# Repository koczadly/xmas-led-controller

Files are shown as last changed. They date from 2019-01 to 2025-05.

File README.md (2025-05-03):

# Alrite?

## Introduction
This repository contains files from a personal project. The aim was to create a small microcontroller-driven LED module to replace a broken incandescent-based fibre optic Christmas tree. This is my first project involving PIC microcontrollers, and the second PCB I've designed; mistakes and questionable design techniques are to be expected.

### Files
- PCB files are in [`hardware`](/hardware/) (KiCad project)
- Software code is in [`firmware`](/firmware/) (MPLAB X project)

Feel free to re-use or modify this project to fit your needs, or use as a reference for PCB design or PIC software development.

## Finished product
A range of final images can be found in the [`media` folder](/media/).

Tree running program 1's animation
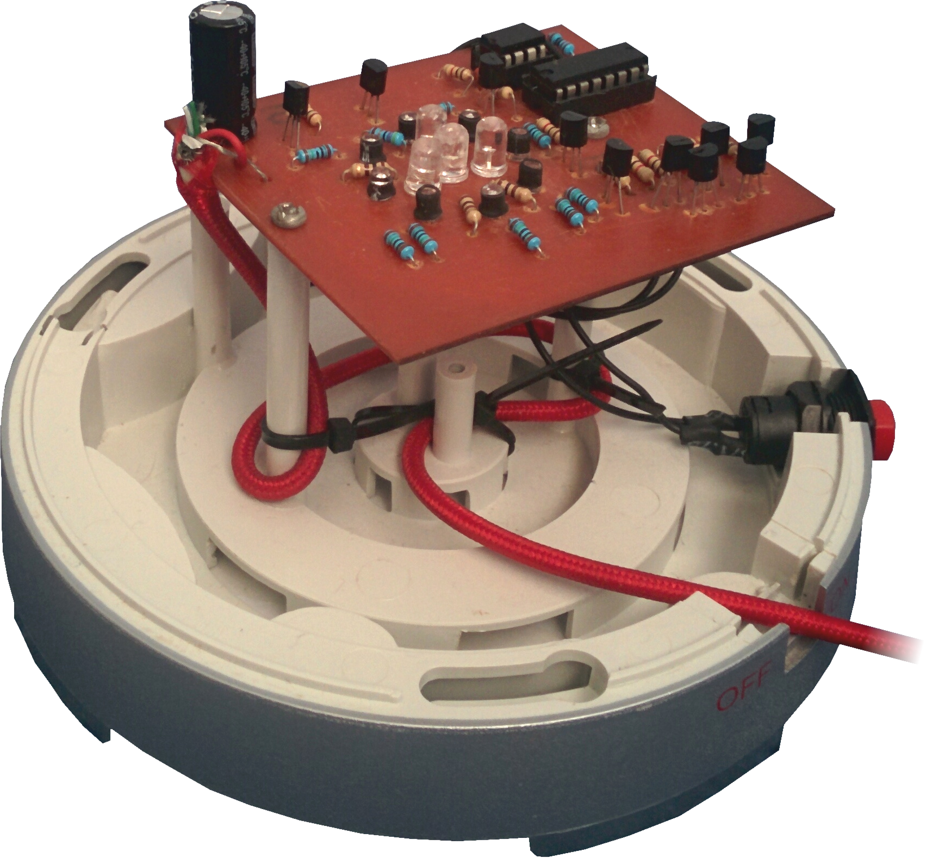
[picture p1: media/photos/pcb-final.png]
Finished PCB


## Bill of materials
MPN | Type | Quantity | Unit cost (GBP) | Purpose
--- | --- | --- | --- | ---
[**PIC12F683**](https://www.microchip.com/wwwproducts/en/PIC12F683) (DIP) | Microcontroller | 1 | £0.45 | Controls visual animations and user input
[**74HC595**](http://www.ti.com/lit/ds/symlink/sn74hc595.pdf) (DIP) | 8-bit Shift Register | 1 | £0.05 | Controls outputs to outer blue LEDs from the MCU
N/A | 3mm Blue LED | 8 | £0.01 | Outer LED ring
N/A | 5mm Green LED | 3 | £0.01 | Inner LEDs (PWM-driven)
N/A | 5mm White LED | 1 | £0.01 | Inner strobing LED
[**2N3904**](https://www.onsemi.com/pub/Collateral/2N3903-D.PDF) (TO-92) | NPN Transistor | 10 | £0.01 | Drives each individual controllable LED group (8x Blue, 1x Green, 1x White)
[N/A](https://www.ebay.co.uk/itm/AC-1-5A-250V-3A-125V-Red-Square-Momentary-SPST-Push-Button-Switch-6-Pcs/183740567110) | SPST Momentary Switch | 1 | £0.30 | User input for changing displayed animation/colour
N/A | 1000μF (25V) Electrolytic Capacitor | 1 | £0.10 | Supply voltage smoothing
N/A | 100nF (50V) Ceramic Capacitor | 1 | £0.01 | Decoupling capacitor for MCU
N/A | 10k Resistor (1/4W) | 1 | £0.001 | Input switch pull-down resistor
N/A | 1k Resistor (1/4W) | 10 | £0.001 | Transistor base current limiters
N/A | 150R Resistor (1/4W) | 8 | £0.001 | Current limiter for blue LEDs
N/A | 120R Resistor (1/4W) | 3 | £0.001 | Current limiter for green LEDs
N/A | 62R Resistor (1/4W) | 1 | £0.001 | Current limiter for white LED

<br>

**Total component cost: £1.15**  
**PCB panel cost (DIY): £0.35**  
**Total cost: £1.50** *(Not including etchant, solder or original tree product)*  

---

## Design notes & constraints
There were various constraints throughout this project, the most difficult one being that I could only produce a single-sided PCB, making overlaps impossible without using space for a 0Ω link. The size of the board was also restricted to *68mm x 92mm*, otherwise the module wouldn't fit into the tree's current plastic base housing. Drill holes also had to be made and inserted at defined locations so the board could easily be screwed into the unit using pre-existing screw mounts from the previous incandescent arrangement.

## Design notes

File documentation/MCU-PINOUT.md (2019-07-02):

# Microcontroller pinout

This project utilises a PIC12f683 microcontroller to control the animations and LEDs.
The pinout is as follows (following pin numbers specified in the datasheet):

Pin # | Name | Configuration | Function
--- | --- | --- | ---
1 | VDD | POWER | +5V power source
2 | GP5 | OUTPUT | Shift register serial data
3 | GP4 | OUTPUT | Shift register latch
4 | GP3 | INPUT | Program button (HIGH to change)
5 | GP2 | OUTPUT | Green LEDs (PWM-driven)
6 | GP1 | OUTPUT | Shift register serial clock
7 | GP0 | OUTPUT | White LED
8 | VSS | POWER | Ground

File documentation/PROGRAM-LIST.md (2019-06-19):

# Effects & animations
The current software version provides a total of 14 patterns, which can be changed by pressing the button (GP3 on U1).
The selected pattern will be retained when the power is cut in EEPROM memory address 0x00.

## List of effects
The following effects are available:
1. Sparkling blue + breathing green + flashing white (fast)
2. Sparkling blue + breathing green + flashing white (slow)
3. Sparkling blue + breathing green
4. Sparkling blue + static green
5. Sparkling blue
6. Breathing green
7. Breathing green + 100% blue
8. Breathing green + 50% blue
9. Static green
10. Static blue
11. Static aqua (green + 100% blue)
12. Static aqua (green + 50% blue)
13. Colour cycle (green/blue)
14. Colour cycle (green/blue/white)

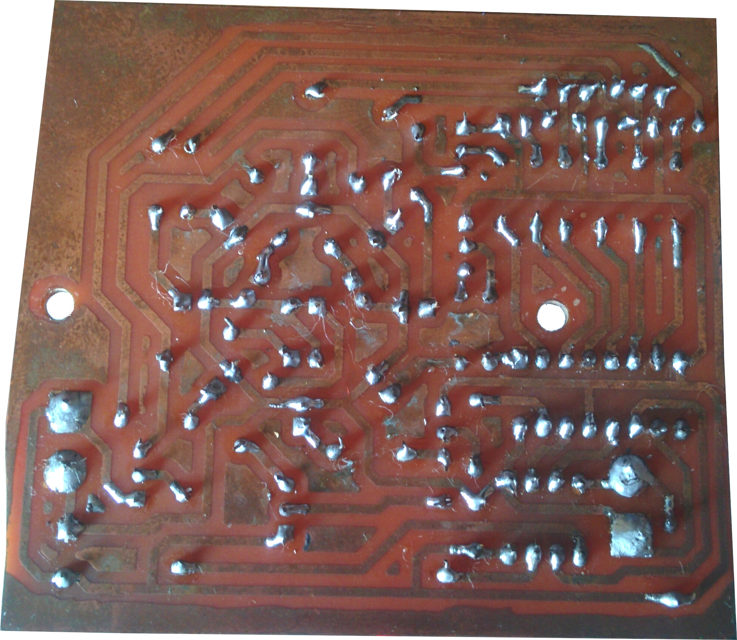
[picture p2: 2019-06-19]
media/photos/pcb-under.jpg

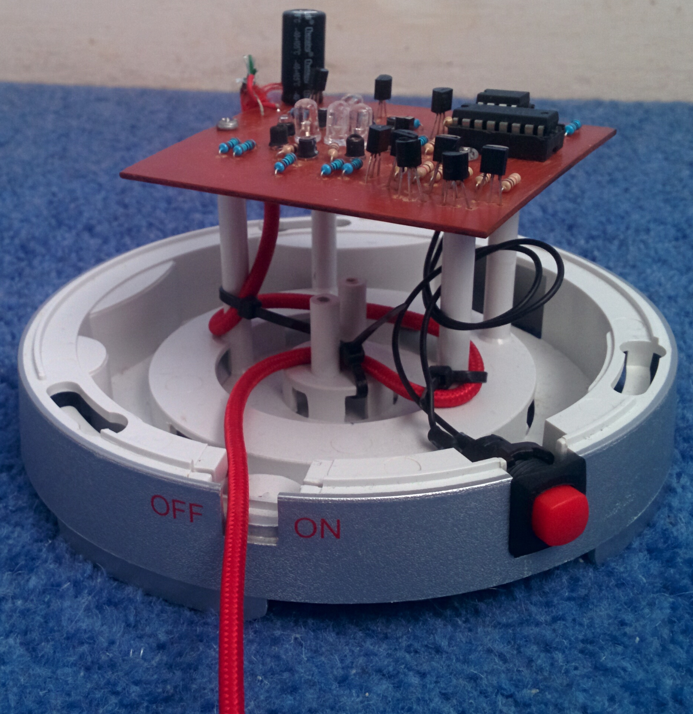
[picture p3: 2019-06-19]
media/photos/pcb-final-2.jpg

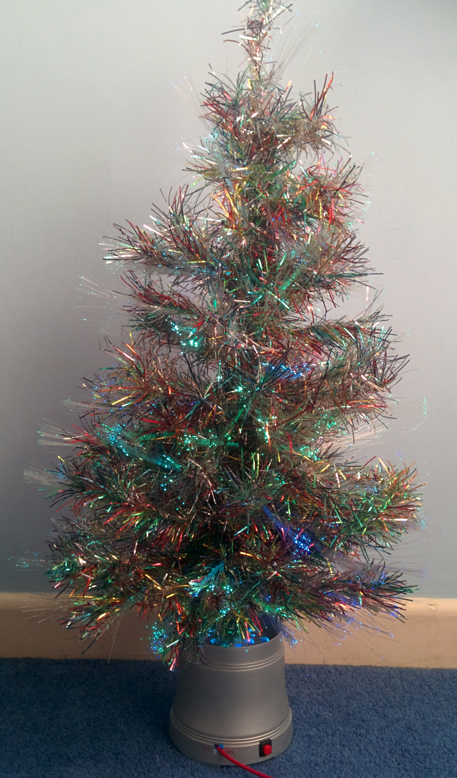
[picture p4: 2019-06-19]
media/photos/tree.jpg

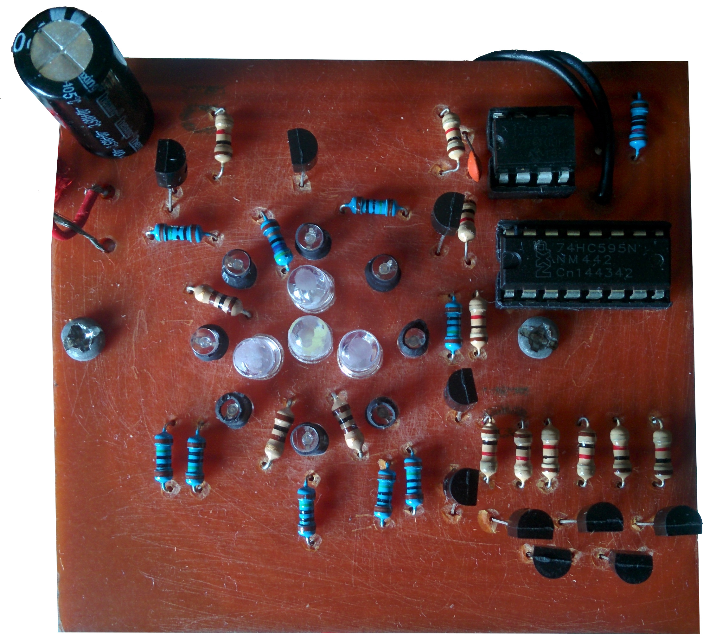
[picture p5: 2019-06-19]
media/photos/pcb-top.jpg

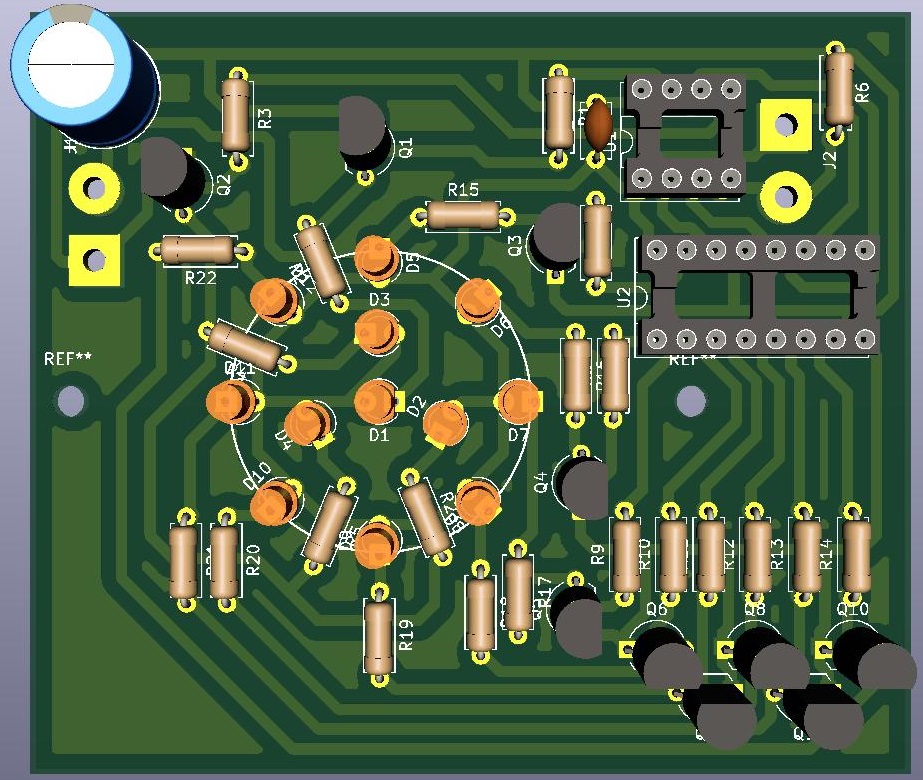
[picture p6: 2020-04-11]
media/renders/pcb-render-top.jpg

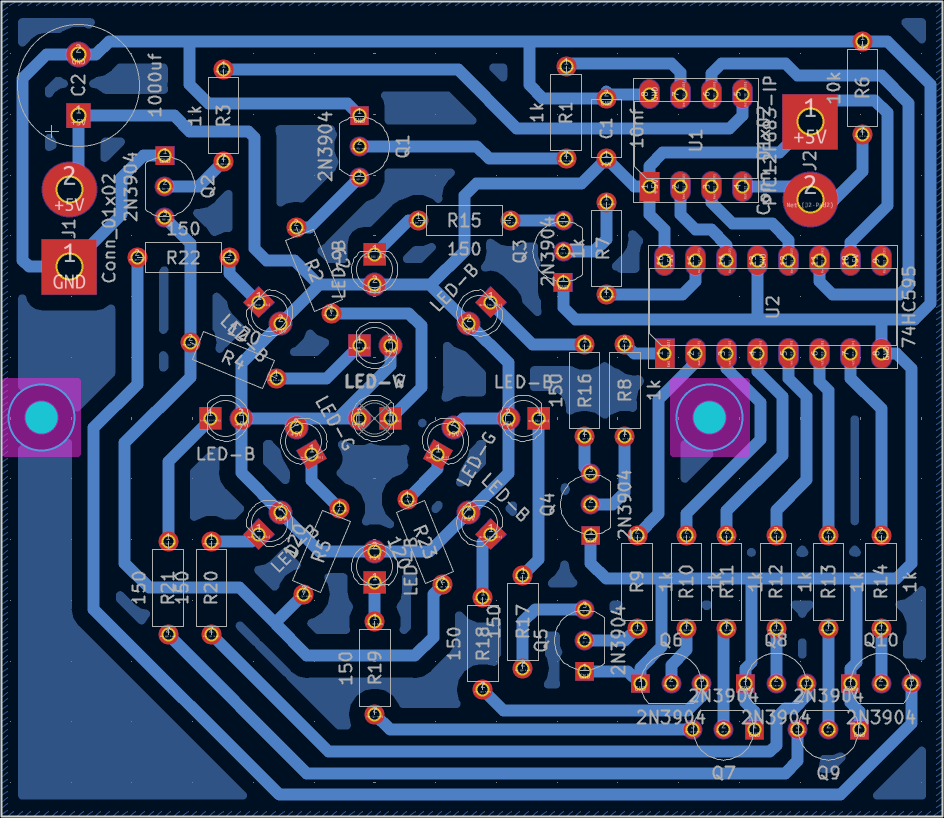
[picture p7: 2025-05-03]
media/renders/pcb-editor.png

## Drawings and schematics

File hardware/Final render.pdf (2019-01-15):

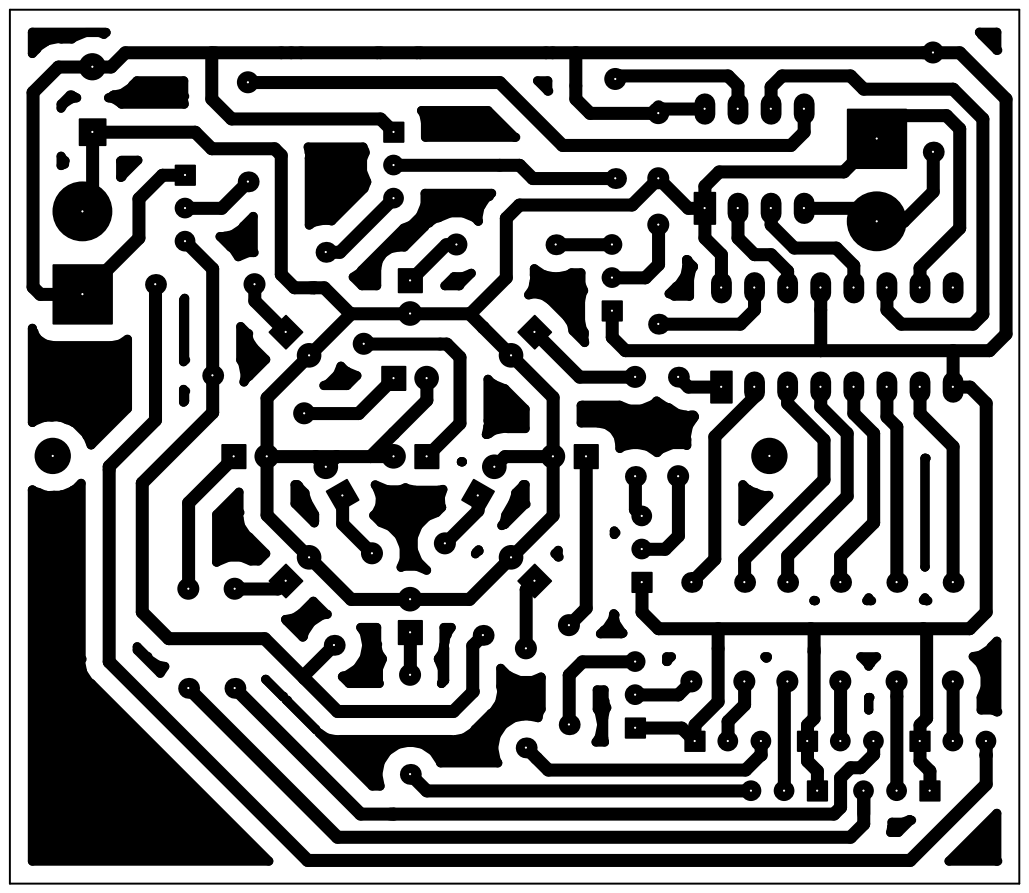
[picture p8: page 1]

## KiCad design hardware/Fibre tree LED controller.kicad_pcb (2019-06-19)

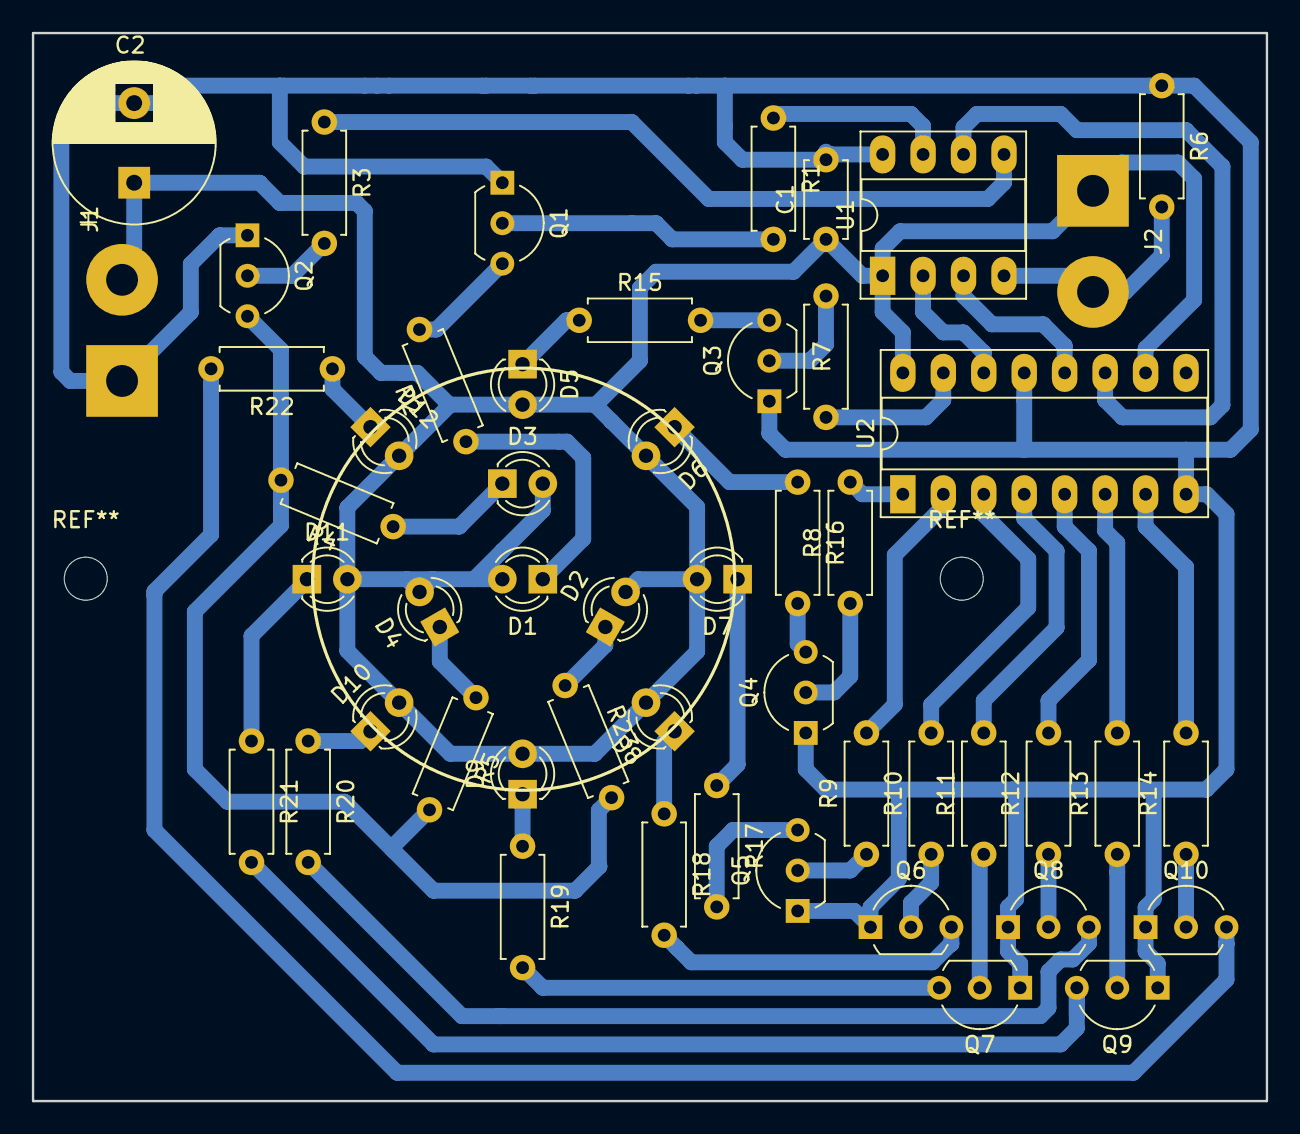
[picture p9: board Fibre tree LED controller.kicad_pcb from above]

Board: 2 copper layers, 77.5 x 67.1 mm, 51 parts (0 on the bottom side), 48 nets.

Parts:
C1: 10nf; C_Disc_D4.7mm_W2.5mm_P5.00mm
C2: 1000uf; CP_Radial_D10.0mm_P5.00mm
D1: LED-W; LED_D3.0mm_FlatTop
D2, D3, D4: LED-G; LED_D3.0mm_FlatTop
D5, D6, D7, D8, D9, D10, D11, D12: LED-B; LED_D3.0mm_FlatTop
J1, J2: Conn_01x02; SolderWirePad_1x02_P7.62mm_Drill2mm
Q1, Q2, Q3, Q4, Q5, Q6, Q7, Q8, Q9, Q10: 2N3904; TO-92L_Inline_Wide
R1, R3, R7, R8, R9, R10, R11, R12, R13, R14: 1k; R_Axial_DIN0207_L6.3mm_D2.5mm_P7.62mm_Horizontal
R2: 62; R_Axial_DIN0207_L6.3mm_D2.5mm_P7.62mm_Horizontal
R4, R5, R23: 120; R_Axial_DIN0207_L6.3mm_D2.5mm_P7.62mm_Horizontal
R6: 10k; R_Axial_DIN0207_L6.3mm_D2.5mm_P7.62mm_Horizontal
R15, R16, R17, R18, R19, R20, R21, R22: 150; R_Axial_DIN0207_L6.3mm_D2.5mm_P7.62mm_Horizontal
U1: PIC12F683-IP; DIP-8_W7.62mm_Socket_LongPads
U2: 74HC595; DIP-16_W7.62mm_Socket_LongPads

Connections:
+5V: C1.1, C2.1, D1.2, D2.2, D3.2, D4.2, D5.2, D6.2, D7.2, D8.2, D9.2, D10.2, D11.2, D12.2, J1.2, J2.1, U1.1, U2.10, U2.16
GND: C1.2, C2.2, J1.1, Q1.1, Q2.1, Q3.1, Q4.1, Q5.1, Q6.1, Q7.1, Q8.1, Q9.1, Q10.1, R6.1, U1.8, U2.8, U2.13
unnamed: D1.1, R2.1
unnamed: D2.1, R23.1
unnamed: D3.1, R4.1
unnamed: D4.1, R5.1
unnamed: D5.1, R15.1
unnamed: D6.1, R16.1
unnamed: D7.1, R17.1
unnamed: D8.1, R18.1
unnamed: D9.1, R19.1
unnamed: D10.1, R20.1
unnamed: D11.1, R21.1
unnamed: D12.1, R22.1
unnamed: J2.2, R6.2, U1.4
unnamed: Q1.2, R1.2
unnamed: Q1.3, R2.2
unnamed: Q2.2, R3.2
unnamed: Q2.3, R4.2, R5.2, R23.2
unnamed: Q3.2, R7.1
unnamed: Q3.3, R15.2
unnamed: Q4.2, R8.1
unnamed: Q4.3, R16.2
unnamed: Q5.2, R9.1
unnamed: Q5.3, R17.2
unnamed: Q6.2, R10.1
unnamed: Q6.3, R18.2
unnamed: Q7.2, R11.1
unnamed: Q7.3, R19.2
unnamed: Q8.2, R12.1
unnamed: Q8.3, R20.2
unnamed: Q9.2, R13.1
unnamed: Q9.3, R21.2
unnamed: Q10.2, R14.1
unnamed: Q10.3, R22.2
unnamed: R1.1, U1.7
unnamed: R3.1, U1.5
unnamed: R7.2, U2.15
unnamed: R8.2, U2.1
unnamed: R9.2, U2.2
unnamed: R10.2, U2.3
unnamed: R11.2, U2.4
unnamed: R12.2, U2.5
unnamed: R13.2, U2.6
unnamed: R14.2, U2.7
unnamed: U1.2, U2.14
unnamed: U1.3, U2.12
unnamed: U1.6, U2.11

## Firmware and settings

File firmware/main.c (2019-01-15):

#include "main.h"
#include "io.h"
#include "patterns.h"


volatile unsigned char initStage = 0;

volatile signed char btnDelayTimerCounter = 15;



void init(void) {
    //Configure oscillator
    OSCCON = 0b01100001;
    
    //Configure IO
    TRISIObits.TRISIO0 = 0; //GP0 | LED-W   White LED
    TRISIObits.TRISIO1 = 0; //GP1 | SRCLK   Serial clock
    TRISIObits.TRISIO2 = 0; //GP2 | LED-G   Green LEDs
    TRISIObits.TRISIO3 = 1; //GP3 | INPUT   Button
    TRISIObits.TRISIO4 = 0; //GP4 | RCLK    Latch
    TRISIObits.TRISIO5 = 0; //GP5 | SER     Serial data
    
    //Initialise shadow register
    GPIOshadow.GPIO = 0x00;
    gpio_latch();
    
    //Timers
    T2CON = 0b1111111; //Timer2 for PWM
    OPTION_REG = 0b01000110; //Timer0, 1:128 prescaler
    
    //CCP1 PWM
    CCP1CON = 0b001100;
    
    //Interrupt registers
    IOC = 0b001000; //IOC for GP3
    INTCONbits.T0IE = 1; //Timer0 interrupt enable
    INTCONbits.GPIE = 1; //GPIO interrupt enable
    INTCONbits.PEIE = 1; //Peripheral interrupt
    INTCONbits.GIE = 1; //Global interrupt enable
}


void main(void) {
    init();
    
    set_led_white(0);
    set_led_green(0x00);
    set_led_blue(0x00);
    
    initStage = 1; //Initialise stage: setup registers
    
    //Load pattern mode from eeprom
    patternMode = eeprom_read(EEPROM_ADDR_MODE);
    
    __delay_ms(10);
    initStage = 2; //Initialise stage: loaded EEPROM
    
    while(1) __delay_ms(1000); //Prevent main() return
}


void interrupt ISR(void) {
    //Timer0
    if(TMR0IF) {
        timer0_isr(); //Handle
        TMR0IF = 0; //Clear flag
    }
    
    //Button (GP3)
    if(GPIF) {
        gpio_isr(); //Handle
        GPIF = 0; //Clear flag
    }
}


//Interrupt for timer0 (15.26 Hz, 1 cycle = 65.53ms)
void timer0_isr(void) {
    if(initStage < 2) return; //Skip if not initialised
    
    if(btnDelayTimerCounter > 0 && !is_btn_pressed()) {
        btnDelayTimerCounter--;
    } else if(btnDelayTimerCounter > BTN_MODE_HOLD_DELAY && btnDelayTimerCounter <= 0 && is_btn_pressed()) {
        if(--btnDelayTimerCounter == BTN_MODE_HOLD_DELAY) {
            pattern_change(); //Change pattern
            btnDelayTimerCounter = BTN_MODE_COOLDOWN_DELAY; //Set button delay
        }
    }
    
    pattern_step();
}


//Interrupt for GPIO
bit wasBtnPressed = 0;

void gpio_isr(void) {
    if(initStage < 2) return; //Skip if not initialised
    
    if(is_btn_pressed()) {
        //Button has been pressed
    } else if(wasBtnPressed) {
        //Button has been released
        btnDelayTimerCounter = BTN_MODE_COOLDOWN_DELAY; //Set button delay
    }
    
    wasBtnPressed = is_btn_pressed();
}

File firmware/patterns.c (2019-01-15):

#include "patterns.h"
#include "io.h"


volatile unsigned char patternMode = 0;
volatile unsigned int patternFrame = -1;


void pattern_change(void) {
    //Change mode and reset animation frame
    patternMode = (patternMode >= 13) ? 0 : patternMode + 1;
    patternFrame = -1;
    
    //Reset LEDs
    set_led_white(0);
    set_led_green(0x00);
    set_led_blue(0x00);
    
    eeprom_write(EEPROM_ADDR_MODE, patternMode); //Store mode in eeprom
}


//  15.26 Hz, 1 frame = 65.53ms

unsigned char randomFlashFrames = 17;

void pattern_step(void) {
    //Animate
    if(patternMode == 0 || patternMode == 1) { //Sparkling blue + breathing green + flashing white
        if(patternFrame == 0) {
            set_led_white(0);
            set_led_blue(0x00);
        }
        
        //White (flash)
        randomFlashFrames--;
        if(randomFlashFrames == 3 && patternMode == 0) {
            set_led_white(1);
        } else if(randomFlashFrames == 2 && patternMode == 0) {
            set_led_white(0);
        } else if(randomFlashFrames == 1) {
            set_led_white(1);
        } else if(randomFlashFrames == 0) {
            set_led_white(0);
            randomFlashFrames = (patternMode == 0 ? (rand(35) + 15) : (rand(120) + 30));
        }
        
        //Blue (sparkle)
        if(patternFrame % (patternMode == 0 ? 4 : 6) == 0) {
            set_led_blue(1 << ((patternFrame / (patternMode == 0 ? 4 : 6)) % 8));
        }
        
        //Green (breathe)
        if(patternFrame <= 255) {
            set_led_green(patternFrame);
        } else if(patternFrame > 270 && patternFrame <= 525) {
            set_led_green(255 - (patternFrame - 270));
        } else if(patternFrame == 536) {
            patternFrame = -1; //Reset frame
        }
    } else if(patternMode == 2) { //Sparkling blue + breathing green
        if(patternFrame == 0) {
            set_led_white(0);
            set_led_blue(0x00);
        }
        
        //Blue (sparkle)
        if(patternFrame % 4 == 0) {
            set_led_blue(1 << ((patternFrame / 4) % 8));
        }
        
        //Green (breathe)
        if(patternFrame <= 255) {
            set_led_green(patternFrame);
        } else if(patternFrame > 270 && patternFrame <= 525) {
            set_led_green(255 - (patternFrame - 270));
        } else if(patternFrame == 536) {
            patternFrame = -1; //Reset frame
        }
    } else if(patternMode == 3 || patternMode == 4) { //Sparkling (sparkling blue, sparkling blue + green)
        if(patternFrame == 0) {
            set_led_green(patternMode == 3 ? 0xFFu : 0x00u);
            set_led_blue(0x00);
            set_led_white(0);
        }
        
        if(patternFrame % 4 == 0) {
            set_led_blue(1 << ((patternFrame / 4) % 8));
        }
        
        if(patternFrame == 32) patternFrame = -1; //Reset frame
    } else if(patternMode >= 5 && patternMode <= 7) { //Breathing green (green, green + 100% blue, green + 50% blue
        if(patternFrame == 0) {
            set_led_blue(patternMode == 5 ? 0x00u : (patternMode == 6 ? 0xFFu : 0x55u));
            set_led_white(0);
        }
        
        if(patternFrame <= 255) {
            set_led_green(patternFrame);
        } else if(patternFrame > 270 && patternFrame <= 525) {
            set_led_green(255 - (patternFrame - 270));
        } else if(patternFrame == 530) {
            patternFrame = -1; //Reset frame
        }
    } else if(patternMode >= 8 && patternMode <= 11) { //Statics (green, blue, aqua (100%), aqua (50%)
        if(patternFrame == 0) {
            set_led_green(patternMode != 9 ? 0xFFu : 0x00u);
            set_led_blue(patternMode == 8 ? 0x00u : (patternMode == 11 ? 0x55u : 0xFFu));
            set_led_white(0);
        }
    } else if(patternMode == 12) {
        if(patternFrame == 0) {
            set_led_white(0);
            set_led_green(0xFF);
            set_led_blue(0x00);
        } else if(patternFrame == 38) {
            set_led_green(0x00);
            set_led_blue(0xFF);
        } else if(patternFrame == 75) {
            patternFrame = -1;
        }
    } else if(patternMode == 13) {
        if(patternFrame == 0) {
            set_led_green(0xFF);
            set_led_blue(0x00);
            set_led_white(0);
        } else if(patternFrame == 12) {
            set_led_green(0x00);
            set_led_blue(0xFF);
            set_led_white(0);
        } else if(patternFrame == 24) {
            set_led_green(0x00);
            set_led_blue(0x00);
            set_led_white(1);
        } else if(patternFrame == 35) {
            patternFrame = -1;
        }
    }
    
    patternFrame++; //Increment frame
}


unsigned short randSeed = 2857;

unsigned char rand(unsigned char upper) {
	return (randSeed = (48271 * randSeed) % 0x7FFF) % upper;
}

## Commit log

2019-01-15 Add hardware (PCB & schem) files
    [Fibre tree LED controller.kicad_pcb, Fibre tree LED controller.sch]
2019-06-19 Add new images and documentation
    [Fibre tree LED controller.kicad_pcb]
2019-11-18 Generate BOM
2019-11-18 Update README to include BOM
2019-11-18 Add specifics to README BOM
